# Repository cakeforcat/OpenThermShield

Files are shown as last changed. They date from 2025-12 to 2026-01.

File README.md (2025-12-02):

# OpenThermShield
OpenTherm adapter/shield for the wemos d1 mini

The primary goal was low cost, speed and manufacturability. The components were gather in the [Edinburgh Hacklab](https://edinburghhacklab.com/) and milled on the PCB mill in 1 day

My boiler is a Vokera Unica 35C
## Photos
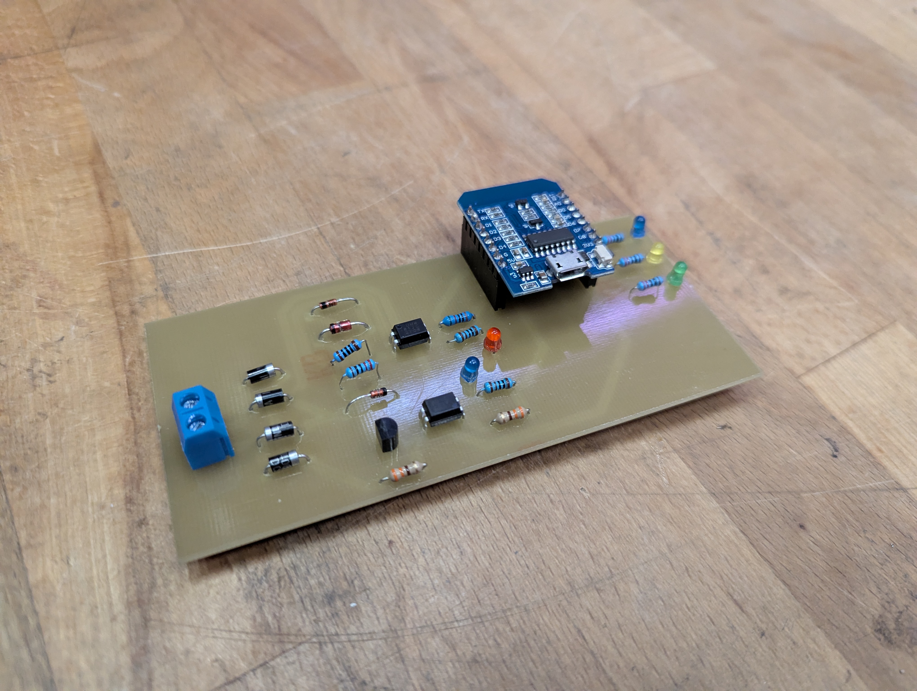
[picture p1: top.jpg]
top

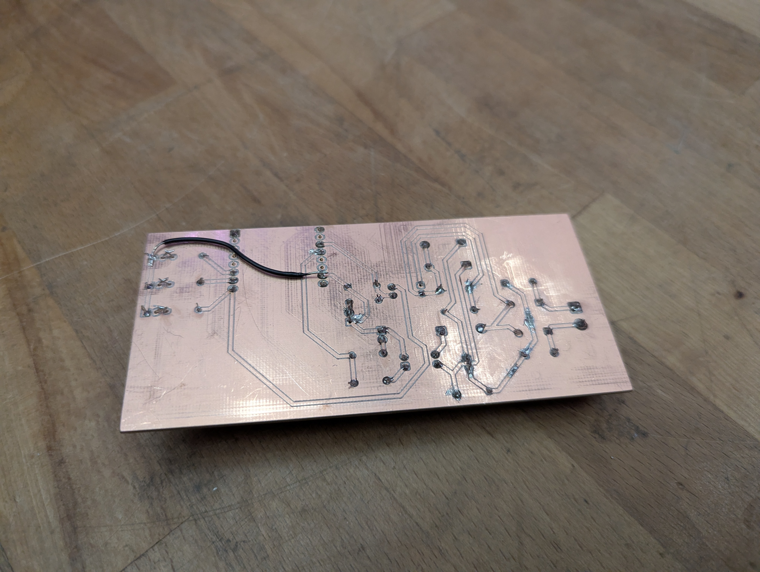
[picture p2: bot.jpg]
bot

## Schematic
The pinout works if you flash the OTGateway firmware and swap the in/out pins in settings (like in the esphome.yaml), but imo esphome works better so if you're running HA highly recommend that approach
schematic
## PCB
PCB
## Case
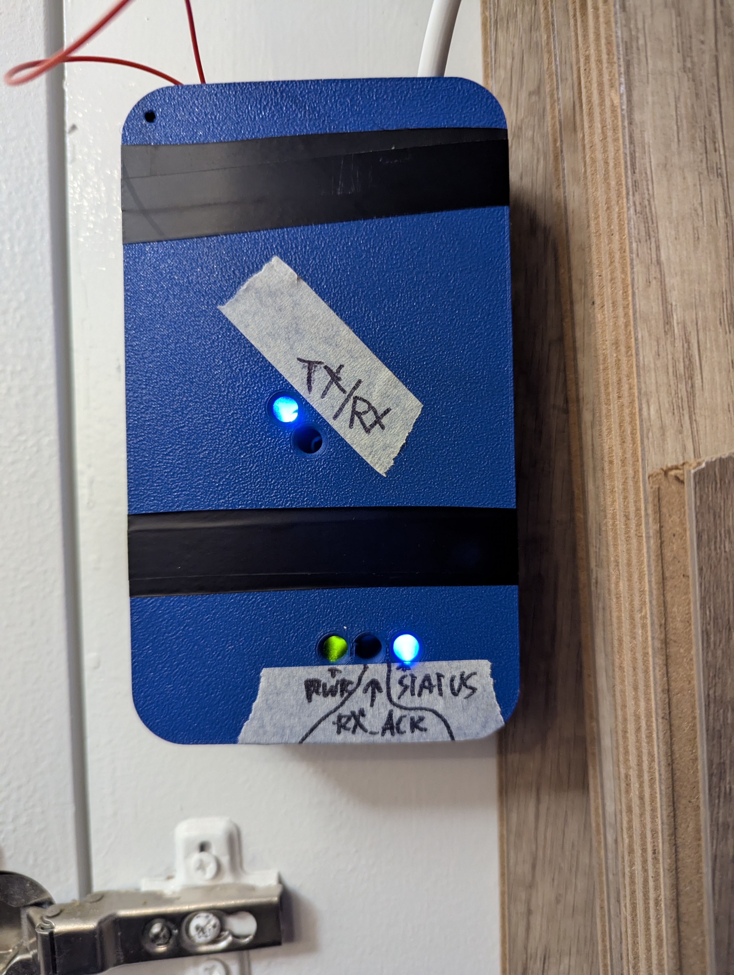
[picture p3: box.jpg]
case

Check out OpenThermShield - Case.3mf (support for bambu-studio). The case was also designed quickly so beware of the cover mount holes being too small. [The USB power supply used](https://www.amazon.co.uk/dp/B0DJVRCLWV)
# esphome.yaml
ESPHome config for the controller

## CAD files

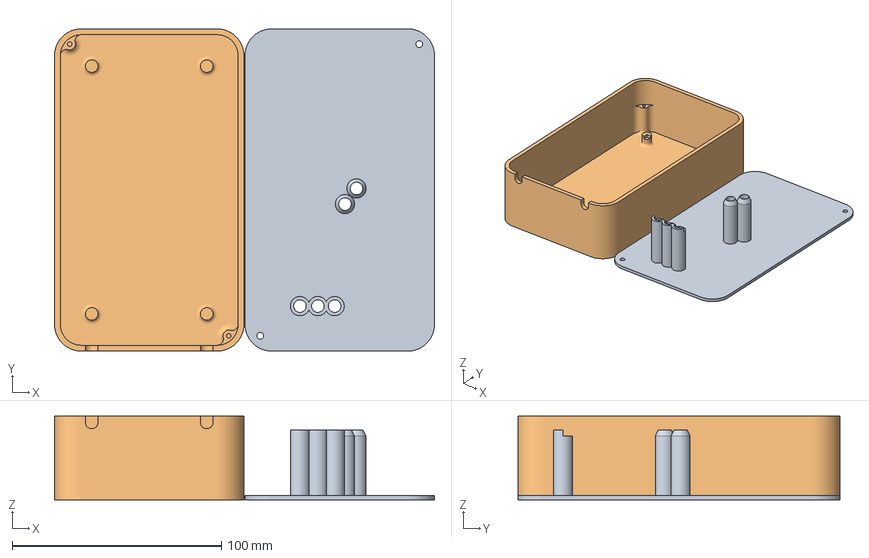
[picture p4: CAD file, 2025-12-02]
OpenThermShield - Case.3mf
181.7 x 154.1 x 40.0 mm

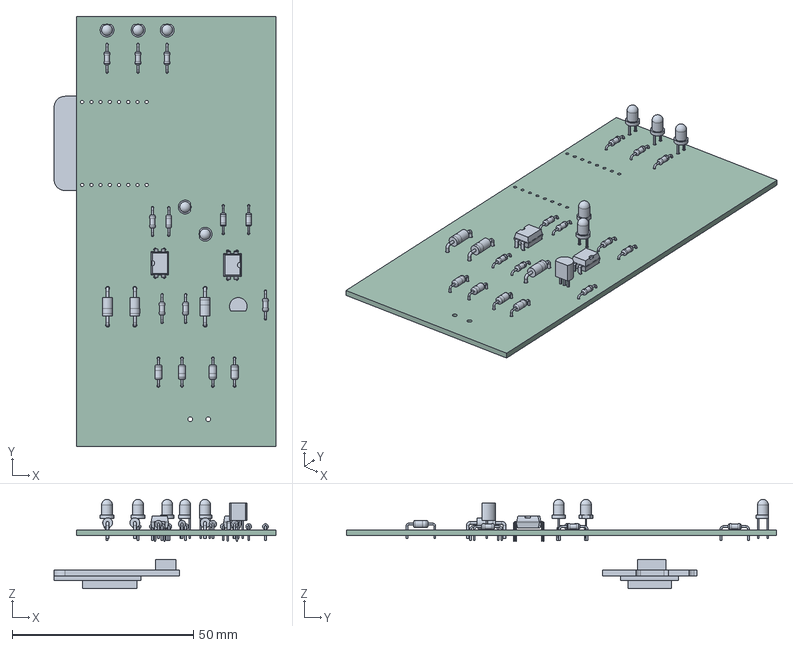
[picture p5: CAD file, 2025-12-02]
OpenThermShield/OpenThermShield.step
61.1 x 118.5 x 24.6 mm
LED_D3.0mm x 5
D_DO-35_SOD27_P7.62mm_Horizontal x 4
R_Axial_DIN0204_L3.6mm_D1.6mm_P7.62mm_Horizontal x 10
DIP-4_W7.62mm x 2
D_DO-41_SOD81_P10.16mm_Horizontal x 3
TO-92_Inline
WEMOS_D1_mini_light
OpenThermShield_PCB

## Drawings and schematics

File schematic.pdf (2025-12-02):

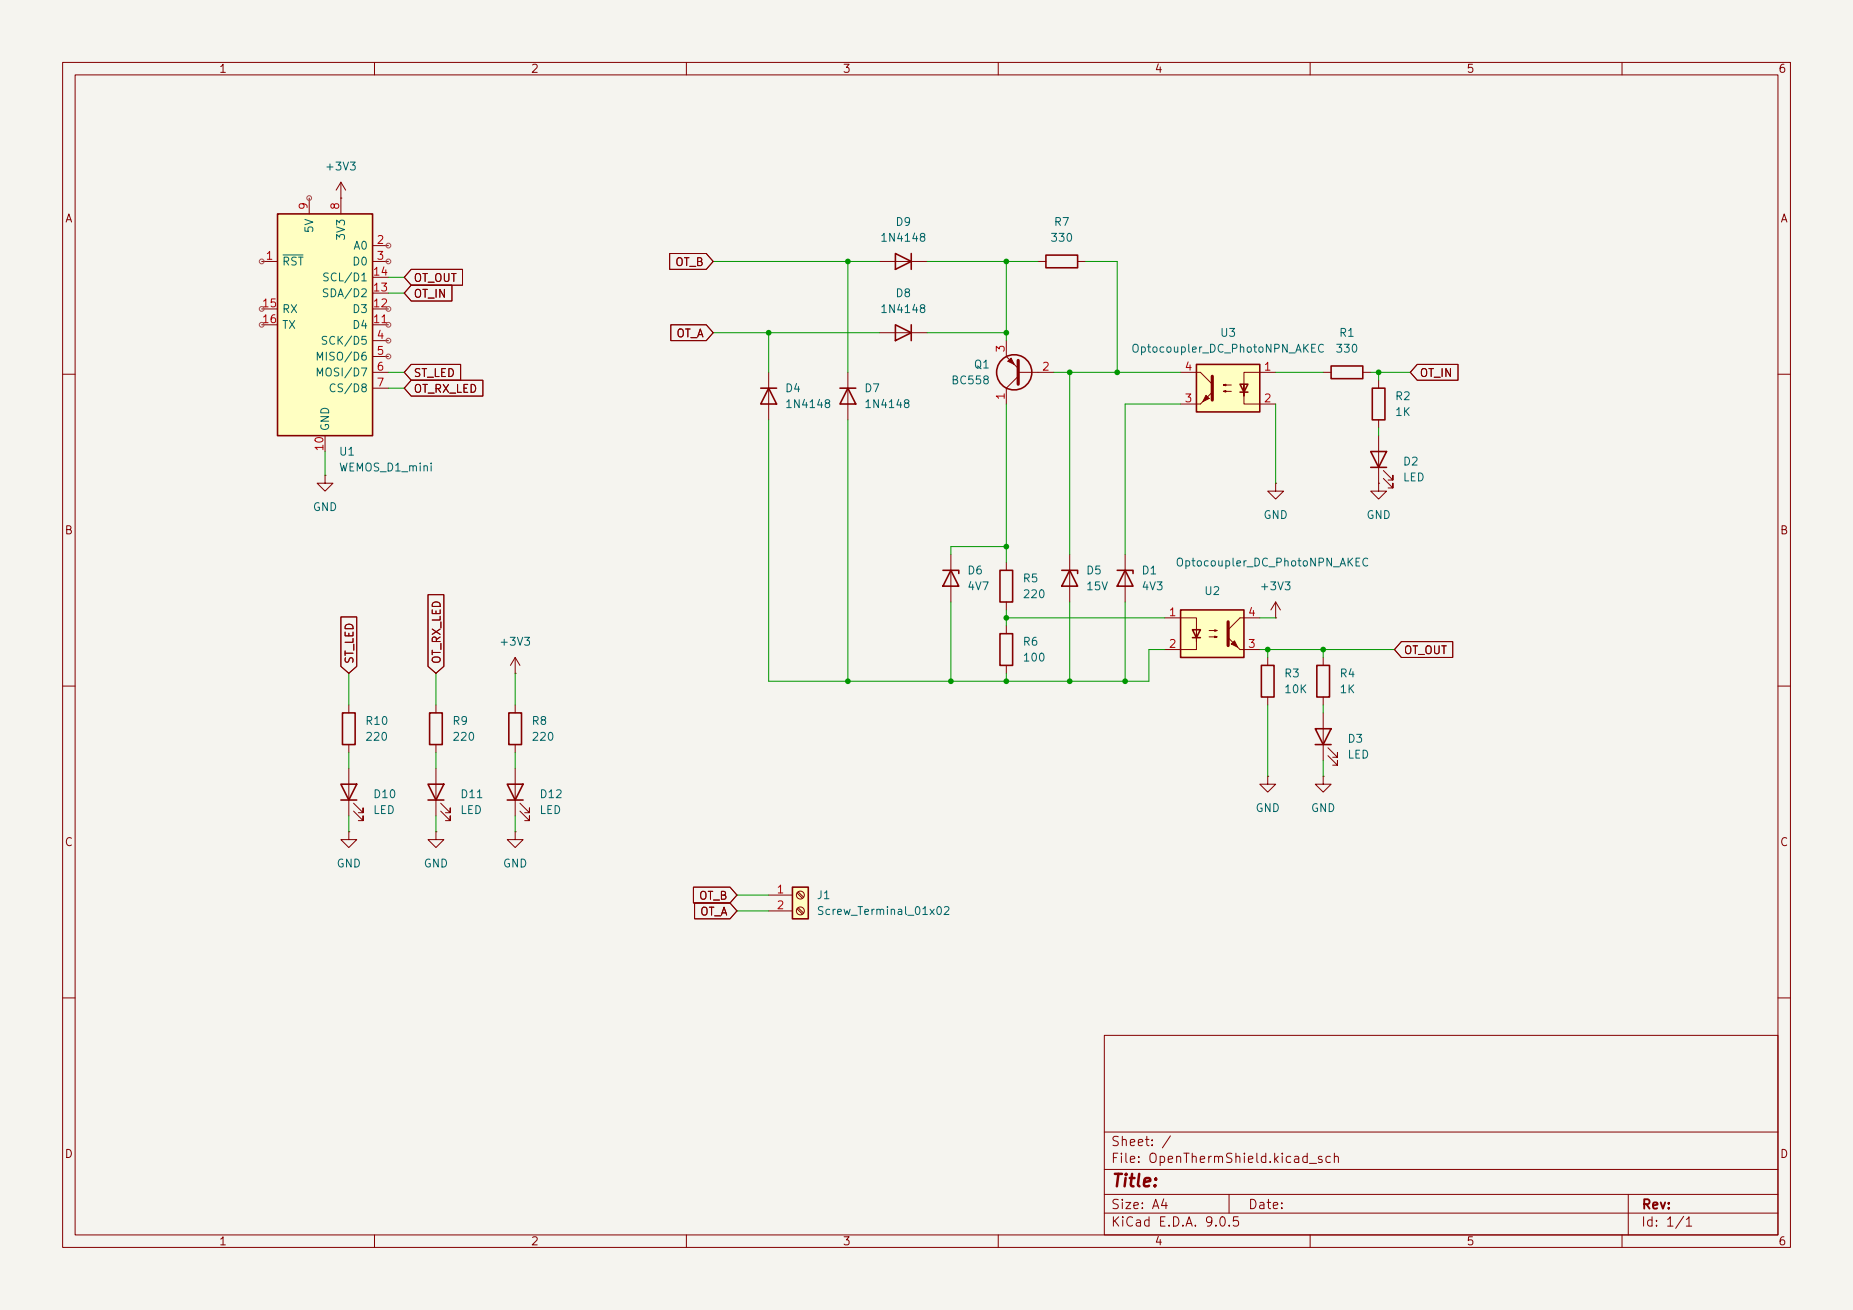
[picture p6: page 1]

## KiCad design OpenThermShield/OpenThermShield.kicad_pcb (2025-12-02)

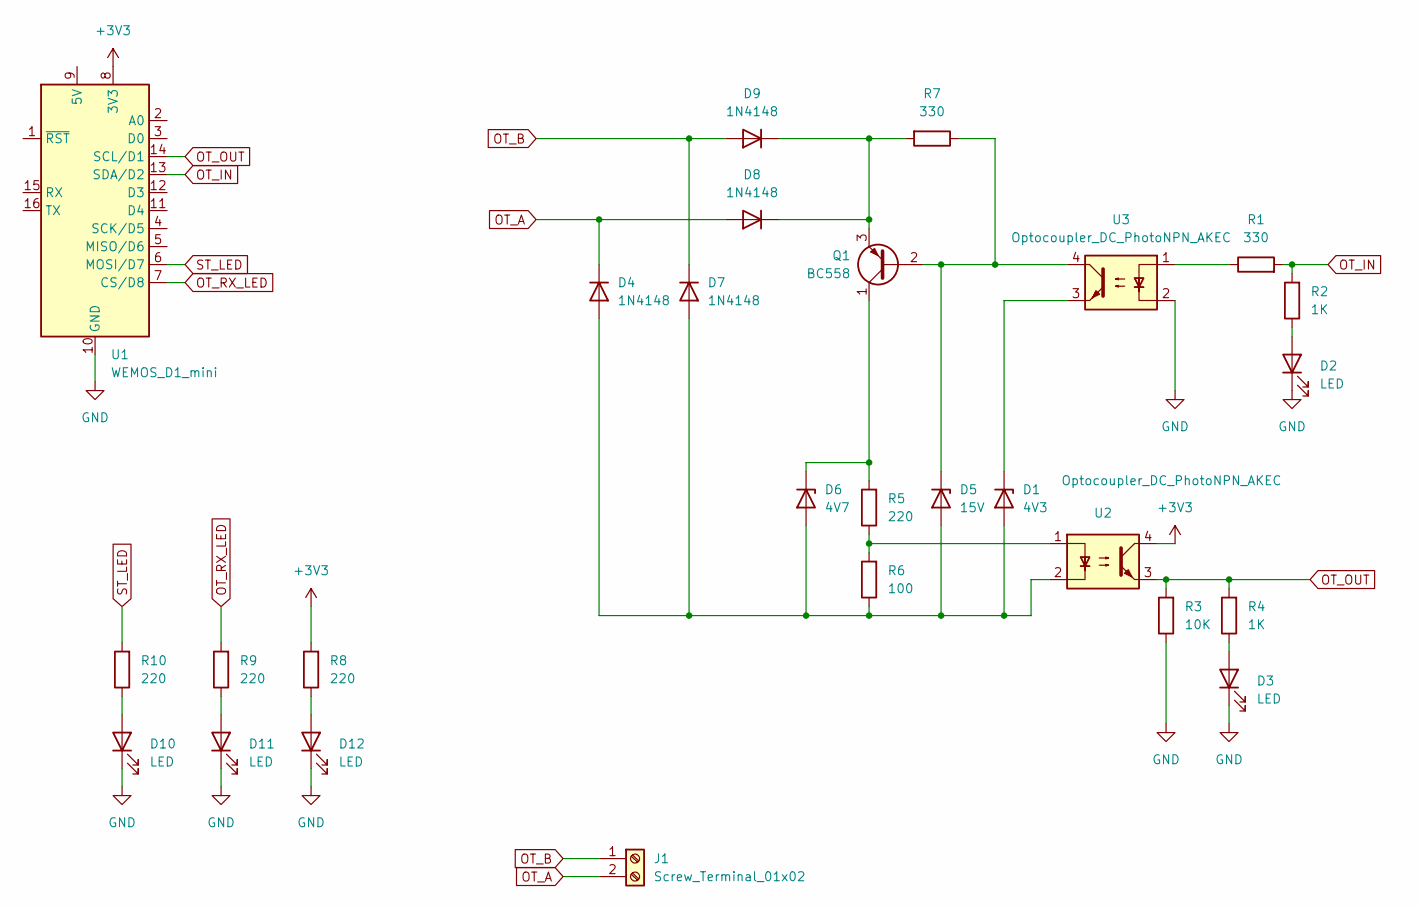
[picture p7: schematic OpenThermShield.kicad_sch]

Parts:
D1: 4V3; D_DO-41_SOD81_P10.16mm_Horizontal
D2, D3, D10, D11, D12: LED; LED_D3.0mm
D4, D7, D8, D9: 1N4148; D_DO-35_SOD27_P7.62mm_Horizontal
D5: 15V; D_DO-41_SOD81_P10.16mm_Horizontal
D6: 4V7; D_DO-41_SOD81_P10.16mm_Horizontal
J1: Screw_Terminal_01x02; TerminalBlock_MaiXu_MX126-5.0-02P_1x02_P5.00mm
Q1: BC558; TO-92_Inline
R1, R7: 330; R_Axial_DIN0204_L3.6mm_D1.6mm_P7.62mm_Horizontal
R2, R4: 1K; R_Axial_DIN0204_L3.6mm_D1.6mm_P7.62mm_Horizontal
R3: 10K; R_Axial_DIN0204_L3.6mm_D1.6mm_P7.62mm_Horizontal
R5, R8, R9, R10: 220; R_Axial_DIN0204_L3.6mm_D1.6mm_P7.62mm_Horizontal
R6: 100; R_Axial_DIN0204_L3.6mm_D1.6mm_P7.62mm_Horizontal
U1: WEMOS_D1_mini; WEMOS_D1_mini_light
U2, U3: Optocoupler_DC_PhotoNPN_AKEC; DIP-4_W7.62mm

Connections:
+3V3: R8.2, U1.8 (3V3), U2.4
GND: D2.1 (K), D3.1 (K), D10.1 (K), D11.1 (K), D12.1 (K), R3.1, U1.10 (GND), U3.2
unnamed: D1.2 (A), D4.2 (A), D5.2 (A), D6.2 (A), D7.2 (A), R6.1, U2.2
unnamed: D1.1 (K), U3.3
unnamed: D2.2 (A), R2.1
unnamed: D3.2 (A), R4.1
unnamed: D5.1 (K), Q1.2 (B), R7.1, U3.4
unnamed: D6.1 (K), Q1.1 (C), R5.2
unnamed: D8.1 (K), D9.1 (K), Q1.3 (E), R7.2
unnamed: D10.2 (A), R10.1
unnamed: D11.2 (A), R9.1
unnamed: D12.2 (A), R8.1
unnamed: R1.1, U3.1
unnamed: R5.1, R6.2, U2.1
OT_A: D4.1 (K), D8.2 (A), J1.2
OT_B: D7.1 (K), D9.2 (A), J1.1
OT_IN: R1.2, R2.2, U1.13 (SDA/D2)
OT_OUT: R3.2, R4.2, U1.14 (SCL/D1), U2.3
OT_RX_LED: R9.2, U1.7 (CS/D8)
ST_LED: R10.2, U1.6 (MOSI/D7)

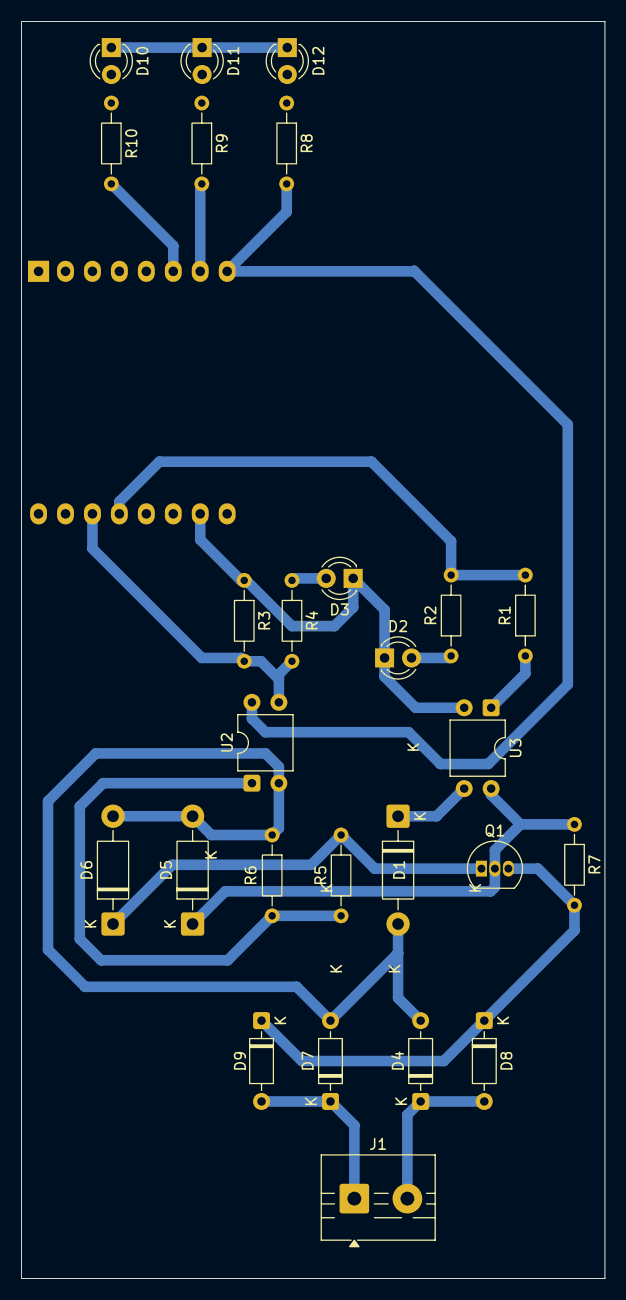
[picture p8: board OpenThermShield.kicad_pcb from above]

Board: 2 copper layers, 55.0 x 118.5 mm, 27 parts (1 on the bottom side), 20 nets.

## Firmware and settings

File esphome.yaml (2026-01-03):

esphome:
  name: mini
  friendly_name: OpenTherm32
  min_version: 2025.9.0
  name_add_mac_suffix: false

esp32:
  board: wemos_d1_mini32
  framework: 
    type: esp-idf


# Enable logging
logger:
  level: DEBUG
  # logs:
  #   opentherm: INFO

# Enable Home Assistant API
api:

# Allow Over-The-Air updates
ota:
- platform: esphome

wifi:
  ssid: !secret wifi_ssid
  password: !secret wifi_password
  min_auth_mode: wpa2

# Declare the phisical pins that OpenTherm adapter is connected to
opentherm:
  in_pin: GPIO22
  out_pin: GPIO21

# Outputs are controlled by some other components, not manually
output:
  - platform: opentherm
    t_set:
      id: ch_setpoint
      max_value: 60
      min_value: 37
      zero_means_zero: true

# Values that can be set maually from HA interface
number:
  - platform: opentherm
    t_dhw_set:
      id: dhw_setpoint
      name: "Hot Water target temperature"
      max_value: 60
      min_value: 37
      restore_value: true
      initial_value: 45

# Switches that can be operated manually from HA interface
switch:
  - platform: opentherm
    ch_enable:
      id: ch_enable
      name: "Central Heating enabled"
      restore_mode: RESTORE_DEFAULT_OFF
    dhw_enable:
      id: dhw_enable
      name: "Hot Water enabled"
      restore_mode: RESTORE_DEFAULT_OFF

# Boiler numeric sensors
sensor:
  - platform: opentherm
    rel_mod_level:
      id: rel_mod_level
      name: "Boiler Relative modulation level"
    t_boiler:
      id: ch_temp
      name: "Boiler Feed Temperature"

  - platform: homeassistant
    id: room_temp
    entity_id: sensor.bte_0005_temperature
    accuracy_decimals: 2
    filters:
      # Push room temperature every second to update PID parameters
      - heartbeat: 1s
      - sliding_window_moving_average:
          window_size: 5
          send_every: 1
  
  - platform: pid
    name: "PID Climate Heat Output (Boiler CH setpoint)"
    type: HEAT

# Boiler binary (True/False) sensors
binary_sensor:
  - platform: opentherm
    ch_active:
      id: ch_active
      name: "Boiler Central Heating active"
    dhw_active:
      id: dhw_active
      name: "Boiler Hot Water active"
    flame_on:
      id: flame_on
      name: "Boiler Flame on"
    fault_indication:
      id: boiler_fault
      name: "Boiler Fault"
      entity_category: diagnostic
    diagnostic_indication:
      id: boiler_diagnostic
      name: "Boiler Diagnostic"
      entity_category: diagnostic

# PID control
#[00:40:26.098][I][pid.autotune:141]: central_heating: PID Autotune:
#[00:40:26.119][I][pid.autotune:142]:   State: Succeeded!
#[00:40:26.119][W][pid.autotune:150]:   Oscillation Frequency is not symmetrical. PID parameters may be inaccurate!
#[00:40:26.120][W][pid.autotune:151]:     This is usually because the heat and cool processes do not change the temperature at the same rate.
#[00:40:26.128][W][pid.autotune:154]:     Please try reducing the positive_output value (or increase negative_output in case of a cooler)
#[00:40:26.141][I][pid.autotune:163]:   Calculated PID parameters ("Ziegler-Nichols PID" rule):
#[00:40:26.150][I][pid.autotune:164]:  
#[00:40:26.162][I][pid.autotune:165]:   control_parameters:
#[00:40:26.162][I][pid.autotune:166]:     kp: 1.04650
#[00:40:26.162][I][pid.autotune:167]:     ki: 0.00045
#[00:40:26.171][I][pid.autotune:168]:     kd: 613.91266
#[00:40:26.171][I][pid.autotune:169]:  
#[00:40:26.179][I][pid.autotune:170]:   Please copy these values into your YAML configuration! They will reset on the next reboot.
#[00:40:26.191][D][pid.autotune:176]:   Alternative Rules:
#[00:40:26.191][D][pid.autotune:208]:     Rule 'Ziegler-Nichols PI':
#[00:40:26.201][D][pid.autotune:209]:       kp: 0.78487, ki: 0.00020, kd: 0.00000
#[00:40:26.201][D][pid.autotune:208]:     Rule 'Pessen Integral PID':
#[00:40:26.212][D][pid.autotune:209]:       kp: 1.22092, ki: 0.00065, kd: 859.47766
#[00:40:26.223][D][pid.autotune:208]:     Rule 'Some Overshoot PID':
#[00:40:26.223][D][pid.autotune:209]:       kp: 0.58081, ki: 0.00025, kd: 908.59070
#[00:40:26.223][D][pid.autotune:208]:     Rule 'No Overshoot PID':
#[00:40:26.230][D][pid.autotune:209]:       kp: 0.34883, ki: 0.00015, kd: 511.59387
#[00:40:26.240][I][pid.autotune:182]: central_heating: Autotune completed
climate:
  - platform: pid
    id: boiler_pid
    name: "Central heating"
    heat_output: ch_setpoint
    default_target_temperature: 20
    sensor: room_temp
    visual:
      min_temperature: 15
      max_temperature: 30
      temperature_step:
        target_temperature: 0.5
        current_temperature: 0.01
    control_parameters: 
      kp: 0.78487
      ki: 0.00020
      kd: 0.0
      output_averaging_samples: 40 # smooth the output over 40 samples
